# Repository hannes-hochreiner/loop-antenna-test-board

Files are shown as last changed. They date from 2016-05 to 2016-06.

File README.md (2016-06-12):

# Test Board for a Loop Antenna (WIP)
Breadboard compatible test board for a loop antenna using an RFM69W module.

## Trace width

There are quite a few on-line impedance calculators for PCB traces.
I chose [one](http://www.eeweb.com/toolbox/microstrip-impedance) at random.
I also compared the results with the trace calculator built into KiCad.
The required figures I looked up on the [OSH Park site](http://docs.oshpark.com/services/) and [Wikipedia](https://en.wikipedia.org/wiki/FR-4).

  * Trace thickness = 1 oz/ft² (1.37 mil)
  * Substrate hight = 63 mil
  * Trace width = 3 mm
  * Substrate dielectric = 4.35
  * Impedance = 50.4 Ohm

A trace width of 3 mm did not seem feasible to me.
However, as it turns out, reducing the substrate hight also reduces the required trace width.
Luckily, OSH Park also offers a [2 oz service with thinner boards](http://docs.oshpark.com/services/two-layer-hhdc/).

  * Trace thickness = 2.8 mil
  * Substrate hight = 30 mil
  * Trace width = 1.4 mm
  * Substrate dielectric = 4.35
  * Impedance = 50.1 Ohm

## Antenna design

I implemented the design equations given in J. Van Niekerk paper in JavaScript.
This helped guide my decisions on the PCB layout.
I decided to cut the corners to avoid 90 degree bends.

## BOM

  * 2 x 1 pF  capacitors (e.g. AVX 08052U1R0BAT2A C0G ESR ~0.1 Ohm at 500 MHz; Farnell: 7568398)
  * 1 x 82 pF capacitor (e.g. AVX 12065A820JAT2A C0G; Farnell: 2332877)
  * 1 x 6-30 pF capacitor (e.g. Murata TZC3P300A110B00 N1200ppm/°C; Farnell: 9528660)
  * 2 x 7 pin header (e.g. WR-PHD Series; Farnell: 2356159)

## References
  * [J. Van Niekerk, et al "Loop Antenna Basics and Regulatory Compliance for Short-Range Radio," microchip.com retrieved 2016-05-06]( http://ww1.microchip.com/downloads/en/DeviceDoc/RFA1%20parts%205%206%20b.pdf)

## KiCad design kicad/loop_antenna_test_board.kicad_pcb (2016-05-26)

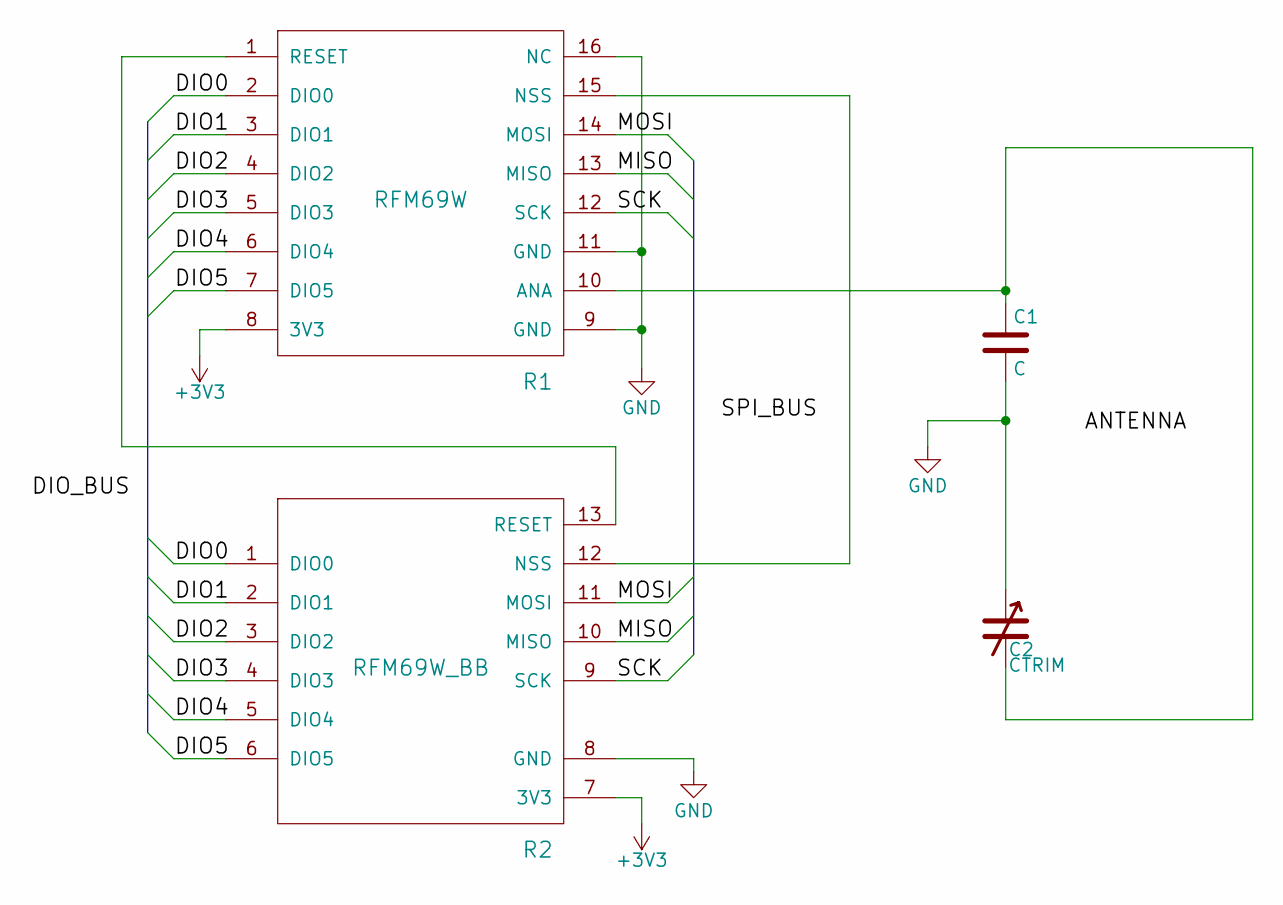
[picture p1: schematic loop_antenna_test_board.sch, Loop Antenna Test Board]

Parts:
C1: C; CAP
C2: CTRIM; CAP_TUNABLE
R1: RFM69W
R2: RFM69W_BB

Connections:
+3V3: R1.8 (3V3), R2.7 (3V3)
/DIO0: R1.2 (DIO0), R2.1 (DIO0)
/DIO1: R1.3 (DIO1), R2.2 (DIO1)
/DIO2: R1.4 (DIO2), R2.3 (DIO2)
/DIO3: R1.5 (DIO3), R2.4 (DIO3)
/DIO4: R1.6 (DIO4), R2.5 (DIO4)
/DIO5: R1.7 (DIO5), R2.6 (DIO5)
/MISO: R1.13 (MISO), R2.10 (MISO)
/MOSI: R1.14 (MOSI), R2.11 (MOSI)
/SCK: R1.12 (SCK), R2.9 (SCK)
GND: C1.2, C2.1, R1.9 (GND), R1.11 (GND), R1.16 (NC), R2.8 (GND)
unnamed: C1.1, C2.2, R1.10 (ANA)
unnamed: R1.1 (RESET), R2.13 (RESET)
unnamed: R1.15 (NSS), R2.12 (NSS)

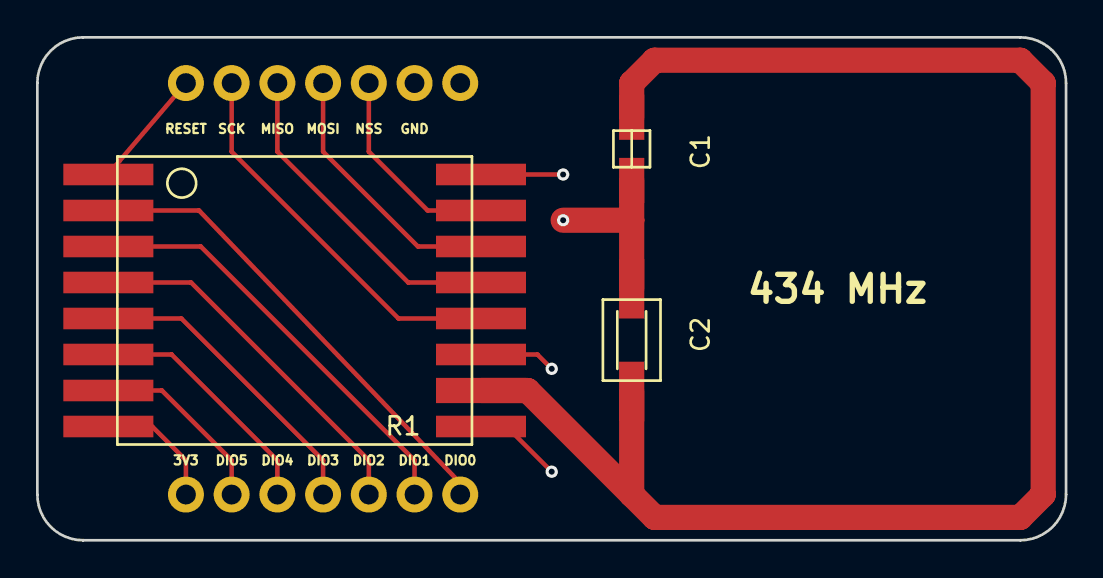
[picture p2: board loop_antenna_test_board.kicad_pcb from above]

Board: 2 copper layers, 57.2 x 27.9 mm, 4 parts (1 on the bottom side), 14 nets.

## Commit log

2016-05-06 added utility functions for the antenna design
2016-05-08 started designing the board
    [loop_antenna_test_board.kicad_pcb, loop_antenna_test_board.sch]
2016-05-08 added board layout
    [loop_antenna_test_board.kicad_pcb, loop_antenna_test_board.sch]
2016-05-08 changed pcb layout
    [loop_antenna_test_board.kicad_pcb]
2016-05-08 rerouted pbc and generated gerbers
    [loop_antenna_test_board-B.Cu.gbl, loop_antenna_test_board-B.Mask.gbs, loop_antenna_test_board-B.SilkS.gbo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]
2016-05-08 updated project
    [loop_antenna_test_board.kicad_pcb]
2016-05-08 smoothed antenna feed
    [loop_antenna_test_board-B.Cu.gbl, loop_antenna_test_board-B.Mask.gbs, loop_antenna_test_board-B.SilkS.gbo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]
2016-05-24 added BOM
2016-05-25 switched to only having two positions for capacitors in the antenna
    [loop_antenna_test_board.kicad_pcb, loop_antenna_test_board.sch]
2016-05-25 reduced the size of the board to match it to the components
    [loop_antenna_test_board.kicad_pcb]
2016-05-26 added a script to help with the design of the antenna
2016-05-26 added outlines for capacitors
    [loop_antenna_test_board.kicad_pcb]
2016-05-26 created gerber files
    [loop_antenna_test_board-B.Cu.gbl, loop_antenna_test_board-B.Mask.gbs, loop_antenna_test_board-B.SilkS.gbo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]
2016-05-26 fixed bottom silk screen
    [loop_antenna_test_board-B.Cu.gbl, loop_antenna_test_board-B.Mask.gbs, loop_antenna_test_board-B.SilkS.gbo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]
2016-06-12 added header to BOM
